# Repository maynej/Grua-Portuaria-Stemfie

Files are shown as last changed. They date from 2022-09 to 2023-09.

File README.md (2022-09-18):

# Grua-Portuaria-Stemfie

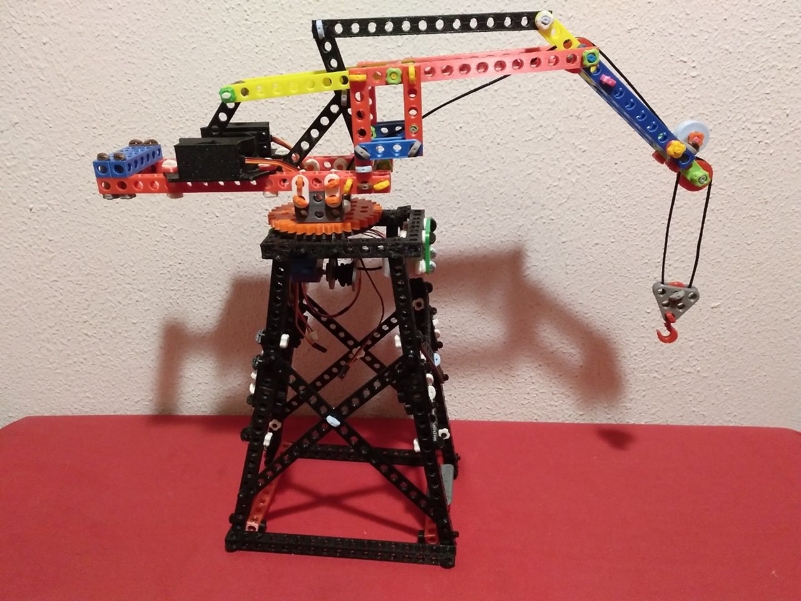
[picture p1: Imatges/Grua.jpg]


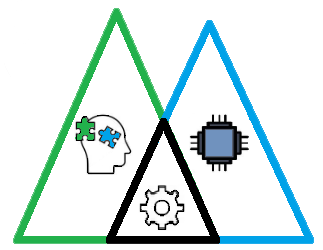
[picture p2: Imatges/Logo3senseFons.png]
Realitzada per [Jordi Mayné](https://github.com/maynej) des de Mechatronic Study 

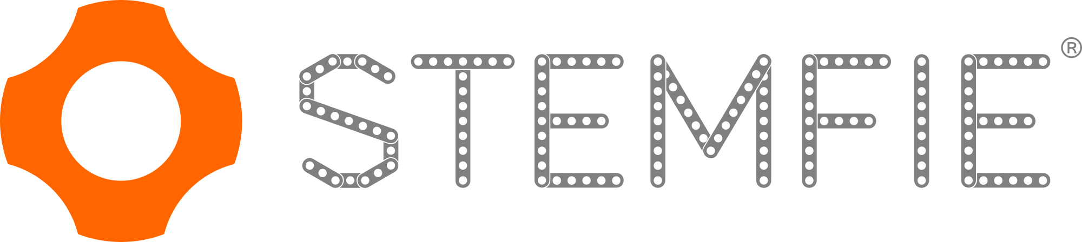
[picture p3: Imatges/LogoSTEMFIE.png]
STEMFIE es un projecte de construcció lliure, que s'imprimeix en 3D (http://stemfie.org) 

Electronics Stemfie es una llibreria STL de suports per tarjes de control, sensors i actuadors amb compatibilitat Stemfie.

[Electronics Suports amb compatibilitat Stemfie](https://github.com/maynej/Electronics-Stemfie), pretén facilitar l'automatització de les construccions amb targes Arduino, Microbit, ESP32 Steamakers... 

La documentació està disponible també en castellà i anglés [en PDF](https://github.com/maynej/Grua-Portuaria-Stemfie/tree/main/DOC)

# Torre base

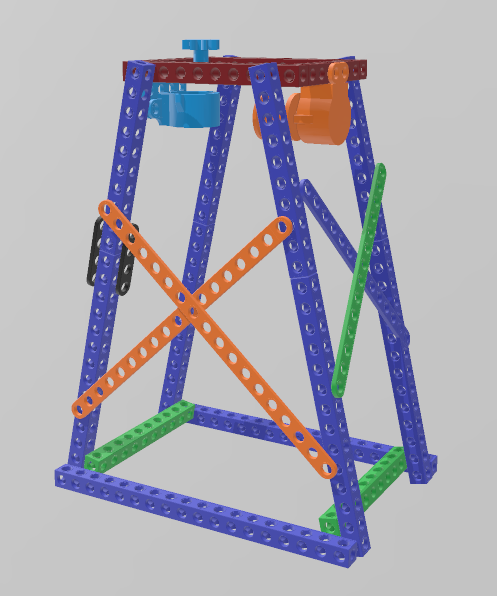
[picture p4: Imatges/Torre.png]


STL per imprimir la Torre Base [aquí](https://github.com/maynej/Grua-Portuaria-Stemfie/tree/main/STL/Base)

# Plataforma giratòria

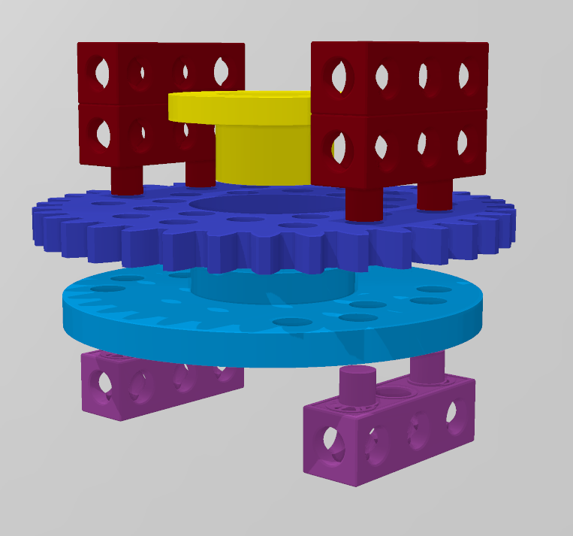
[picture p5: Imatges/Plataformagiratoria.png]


STL per imprimir la Plataforma Giratòria [aquí](https://github.com/maynej/Grua-Portuaria-Stemfie/tree/main/STL/PlataformaGiratoria)

# Ploma

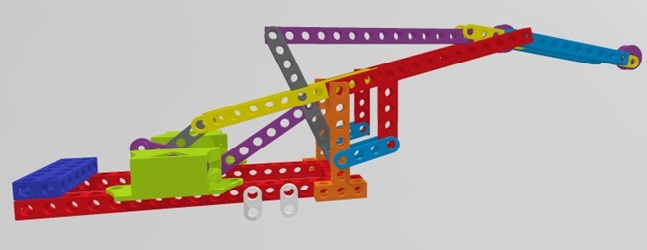
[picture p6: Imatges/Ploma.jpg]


STL per imprimir la Ploma articulada [aquí](https://github.com/maynej/Grua-Portuaria-Stemfie/tree/main/STL/Ploma)

# Ganxo

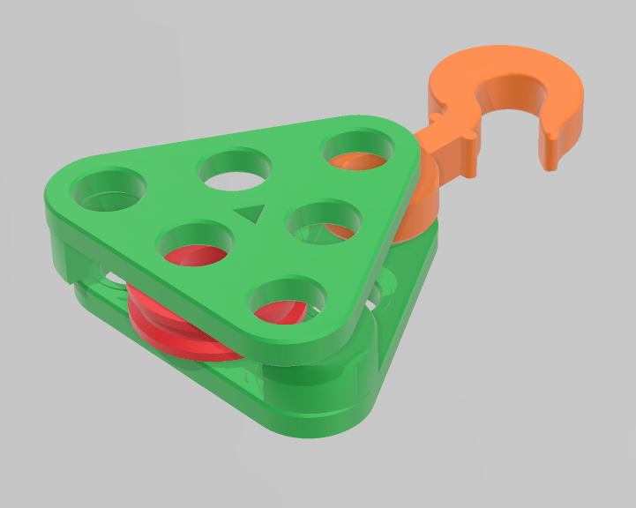
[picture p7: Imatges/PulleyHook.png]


STL per imprimir el Ganxo [aquí](https://github.com/maynej/Grua-Portuaria-Stemfie/tree/main/STL/Ganxo)

## Mesurador Stemfie 

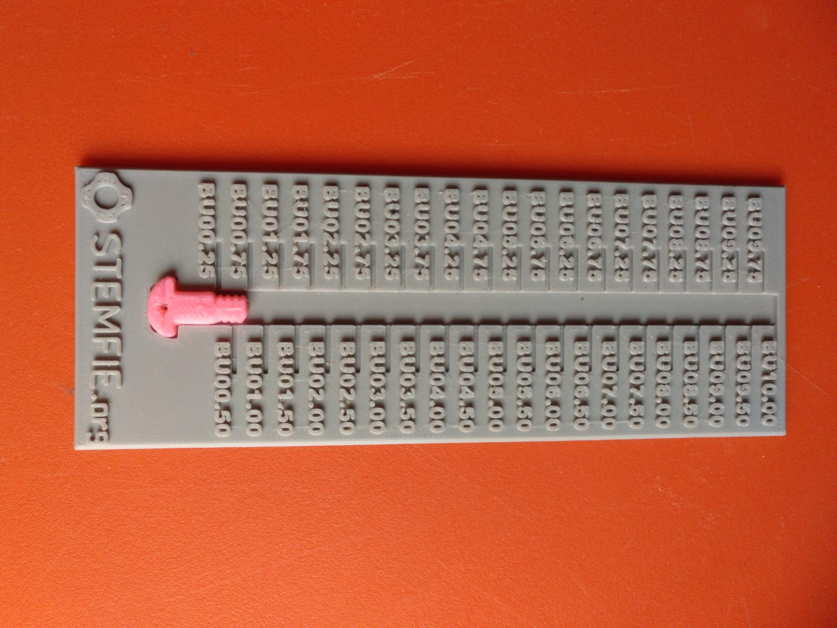
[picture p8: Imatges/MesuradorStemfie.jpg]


Descripció    | Opcional     | Arxiu         
------------- | ------------ | ----- 
Mesurador Cargols | 1  | [Mesurador](STL/MesuraStemfie2.stl)

## Llicència

Creative Commons Attribution-NoComercial-ShareAlike 4.0 International (CC BY-NC-SA 4.0)

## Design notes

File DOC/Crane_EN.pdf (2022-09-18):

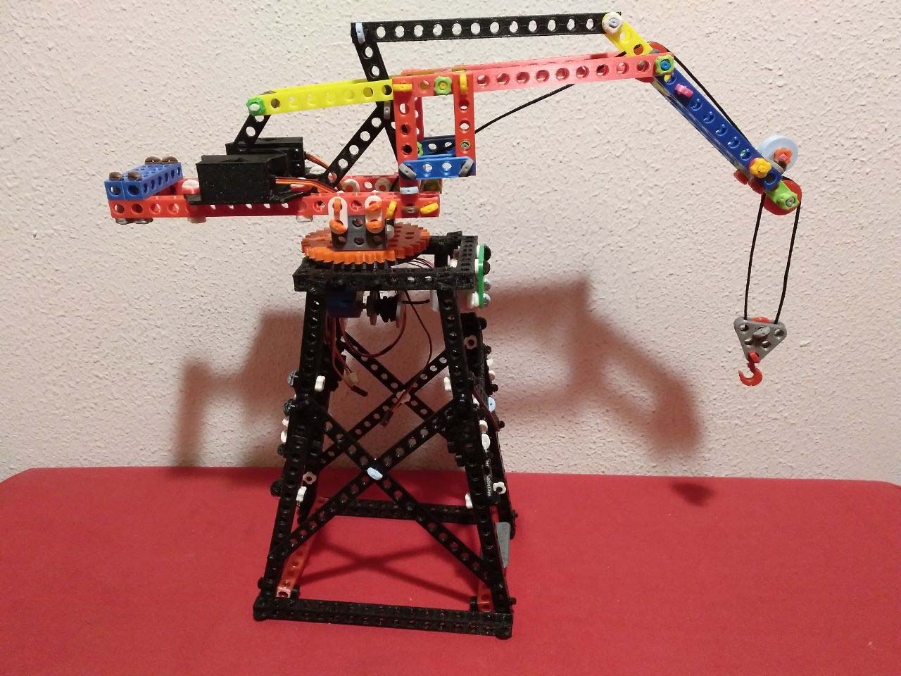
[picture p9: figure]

PORT CRANE – 2022 | 1 | JORDI MAYNE

## Port crane

This harbor crane is a reproduction with Stemfie parts(www.stemfie.org). It allows to be a tool for assembly skills and programming the control, the structure is formed by a tower base, the articulated boom and counterweight.

The screws are pieces that are not currently used in commercial toys, the pieces are joined based on easy assemblies, but the people lose the opportunity to gain hand skill and dexterity to place the screws and turn the nuts.

The control is composed by two power servomotors for to move the articulated boom, a stepper motor for the 360 degree rotation and another for the rope for rope winding drum.

These motors are controlled by an Arduino Uno or ESP32 Steamakers board and two joysticks, LED light to indicate movements and a buzzer.

Alternatively, it can be controlled via a Bluetooth mobile phone app.

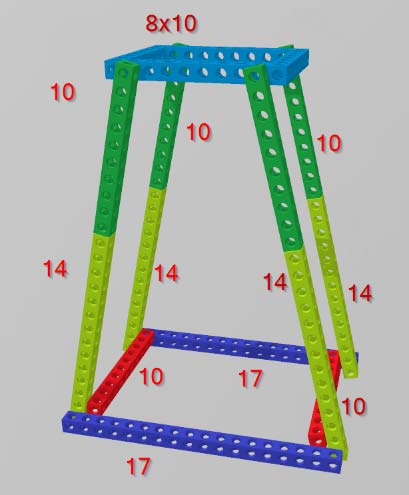
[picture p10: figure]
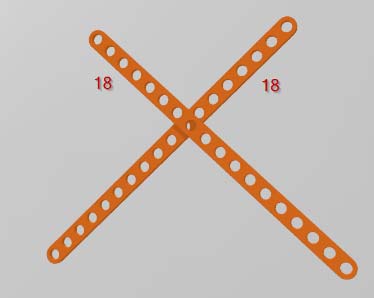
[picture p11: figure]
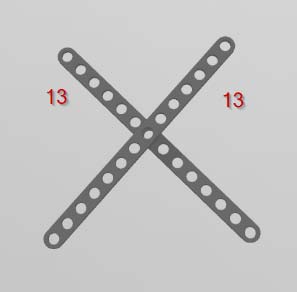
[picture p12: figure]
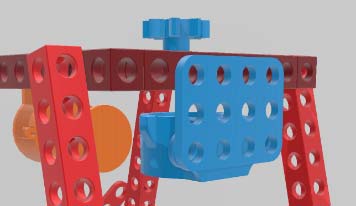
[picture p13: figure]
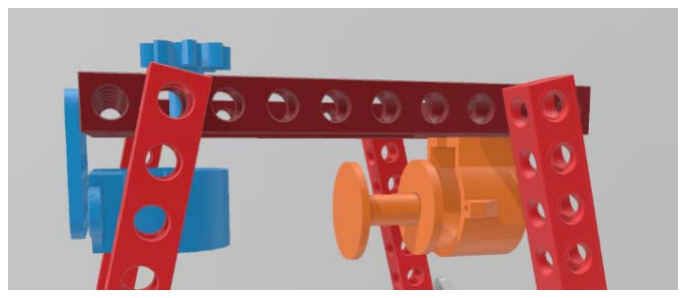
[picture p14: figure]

PORT CRANE – 2022 | 2 | JORDI MAYNE

### Mounting

Tower

The structure will also contain the power supply, the control unit and the stepper motors. In the upper part of this structure, the rotating platform will be housed, which allows turn 360‐degree and supports the articulated boom.

2 Beam17 | 4 ScrewBU02.00 | 4 Nuts
4 Beam14 | 4 ScrewBU02.00 | 4 Nuts
6 Beam10 | 4 ScrewBU02.00 | 4 Nuts

1 Base8x10

16 Brace4 | 16 ScrewBU01.50 | 16 Nuts
4 Brace18 | 2 ScrewBU00.50 | 8 ScrewBU01.25 | 10 Nuts
4 Brace13 | 2 ScrewBU00.50 | 8 ScrewBU01.25 | 10 Nuts
4 ScrewBU02.00 | 4 Nuts

Stepper Motors

Platform Motor

1 28BYJ‐48_2H_Stemfie | Gear28BYJ‐48_130mm
1 STR_STD_BRM‐4x3 | 2 ScrewBU01.50 | 2 Nuts 2 Washer2.5mm

Pulley Hook Motor

28BYJ‐48_4H_Stemfie | 1 Spool28BYJ‐48 | 2 ScrewBU01.25 2 Nuts

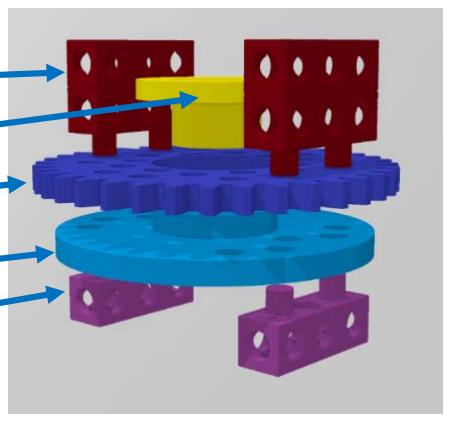
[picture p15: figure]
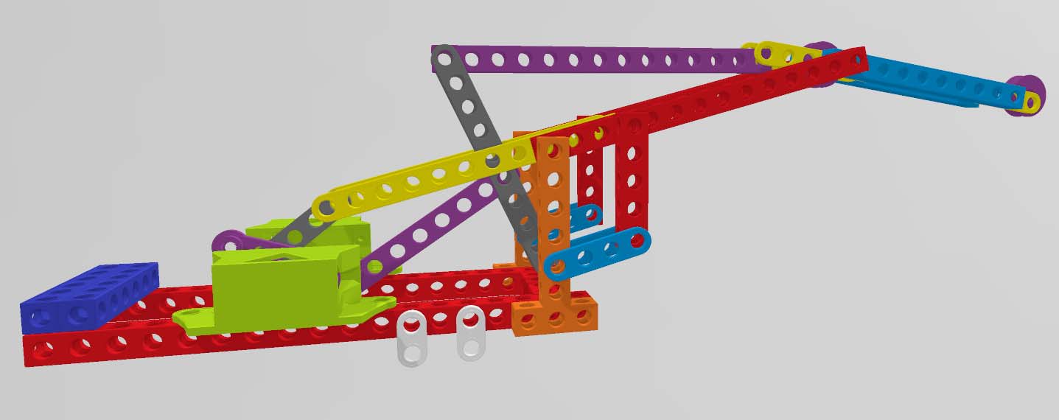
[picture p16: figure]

PORT CRANE – 2022 | 3 | JORDI MAYNE

Rotating Platform

This platform allows to rotate 360 degrees the articulated boom, it is fixed to the structure base. The yellow part should be glued to the light blue disc to ensure that the dark blue gear can rotate freely and will not come apart. The blocks are inserted in the disc and in the gear, they will serve to seat the base8x10 and the articulated boom.

2 BlocGrua3x2

1 TapEngranatgeGrua

1 EngranatgeGrua

1 DiscEngranatge

2 BlocGrua3x1

These parts have been specially designed for this mount, but comply with Stemfie compliances.

Articulating boom and counterweight

The crane boom is an articulated boom type and the counterweight area contains two servomotors for the movements of articulated boom.

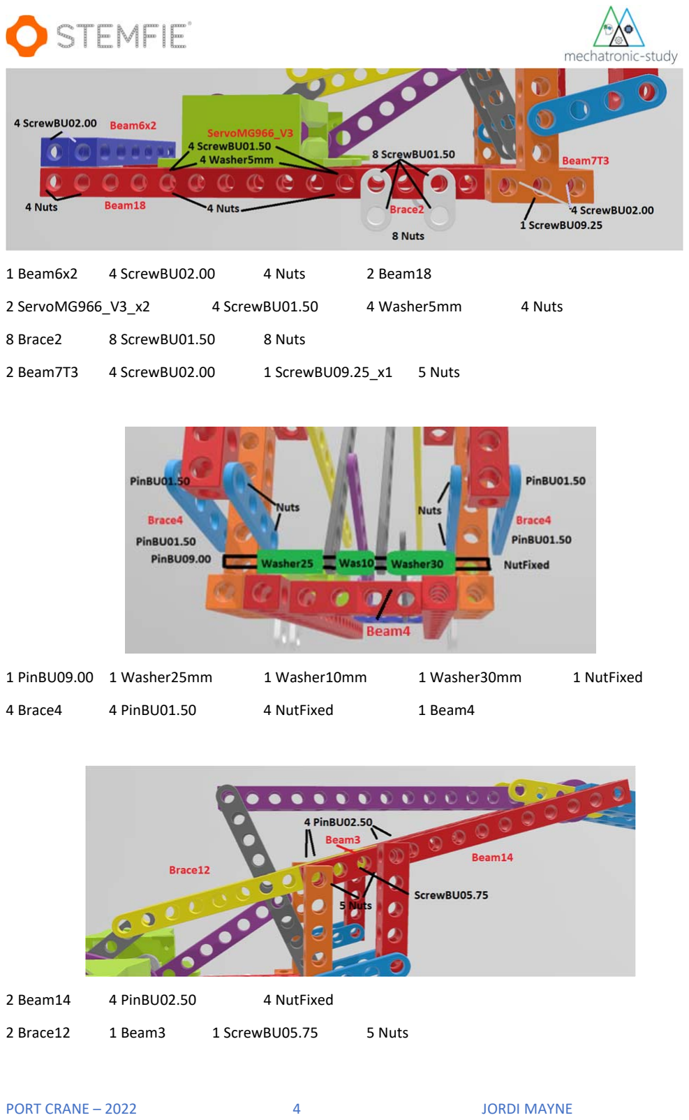
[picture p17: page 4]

PORT CRANE – 2022 | 4 | JORDI MAYNE
1 Beam6x2 | 4 ScrewBU02.00 | 4 Nuts | 2 Beam18
2 ServoMG966_V3_x2 | 4 ScrewBU01.50 | 4 Washer5mm | 4 Nuts
8 Brace2 | 8 ScrewBU01.50 | 8 Nuts
2 Beam7T3 | 4 ScrewBU02.00 | 1 ScrewBU09.25_x1 | 5 Nuts
1 PinBU09.00 1 Washer25mm | 1 Washer10mm | 1 Washer30mm | 1 NutFixed
4 Brace4 | 4 PinBU01.50 | 4 NutFixed | 1 Beam4
2 Beam14 | 4 PinBU02.50 | 4 NutFixed
2 Brace12 | 1 Beam3 | 1 ScrewBU05.75 | 5 Nuts

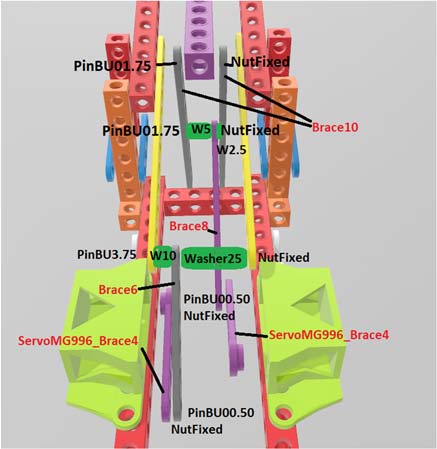
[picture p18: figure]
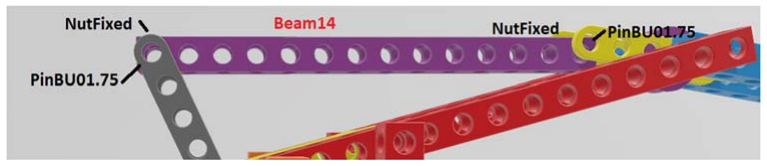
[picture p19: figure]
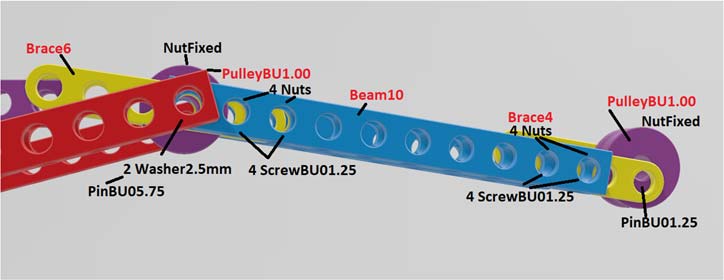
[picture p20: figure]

PORT CRANE – 2022 | 5 | JORDI MAYNE
1 PinBU01.75 | 1 NutFixed | 2 Brace10
1 PinBU01.75 | 1 Washer5mm | 1 Brace8 | 1Washer2.5mm | 1 NutFixed
1 PinBU03.75 | 1 Washer10mm | 1 Brace6 | 1 Washer25mm | 1 NutFixed
2 ServoMG996_Brace4 | 2 PinBU00.50 2 NutFixed
1 Beam14 | 2 PinBU01.75 | 2 NutFixed
2 Beam10 | 1 PinBU05.75 1 Washer2.5mm 1 PulleyBU1.00 1 Washer2.5mm 1 NutFixed
2 Brace6 | 4 ScrewBU01.25 | 4 Nuts
2 Brace4 | 4 ScrewBU01.25 | 4 Nuts | 1 PulleyBU1.00 | PinBU01.25 | 1 NutFixed

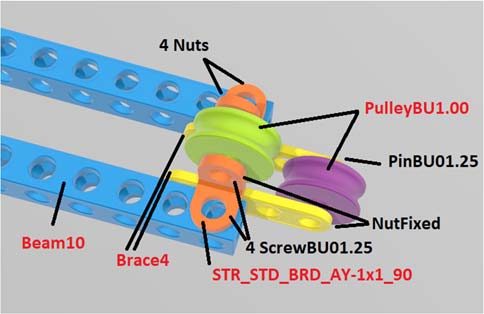
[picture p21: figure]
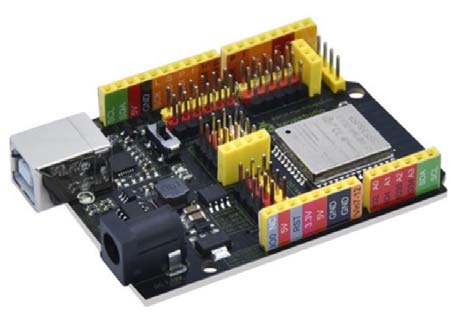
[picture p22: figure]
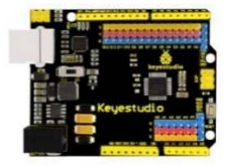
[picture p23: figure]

PORT CRANE – 2022 | 6 | JORDI MAYNE

Improvement of hook rope

2 STR_STD_BRD_AY‐1x1_90 4 ScrewBU01.25 4 Nuts | 1 PulleyBU1.00 | 1 PinBU01.25 1 NutFixed

### Unit Control

Arduino UNO | ESP32 Steamakers

### Software used

http://www.arduinoblocks.com/

PORT CRANE – 2022 | 7 | JORDI MAYNE

https://www.bigrentz.com/blog/what‐is‐a‐crane‐boom

https://www.bigrentz.com/blog/types‐of‐cranes

https://www.curioushistory.com/history‐of‐the‐crane‐from‐inventions‐to‐improvements/

PORT CRANE – 2022 | 8 | JORDI MAYNE

Port cranes play a vital role in day‐to‐day port operations.

# Port Cranes: Everything You Need to Know

## Port cranes play a vital role in day-to-day port operations. Without the help of these cranes, containers can’t be stacked in the yard or loaded on the vessel. There are two types of port cranes: quay cranes and yard

cranes.

## - Quay Cranes: These types of cranes are used to work on containers from ship to shore and shore to ship and are therefore also known as ship-to-shore cranes (STS). Quay cranes are located

along the quayside where container ships are easily accessible.

## - Yard Cranes: These types of cranes are primarily located in the port’s container yard, and move laden containers from the yard to trailers. While there are several types of yard cranes, the most common ones are Rail-Mounted Gantry Cranes (RMG) and

Rubber-Tired Gantry Cranes (RTG).

## When it comes to ship-to-shore port cranes, there are two types: the high profile (with an A-frame) and the low profile. Though they function the same way, it is during the container port design process where the crane

type is decided, based on suitability.

## The low profile crane features a fixed boom to load containers off and onto the vessel. It’s designed and used for scenarios where the seaport is near an airport so that aircrafts are not distracted or blocked by the

cranes.

## On the other hand, high profile port cranes have a hinged boom that

allows for easier ship navigation when berthing or leaving the dock.

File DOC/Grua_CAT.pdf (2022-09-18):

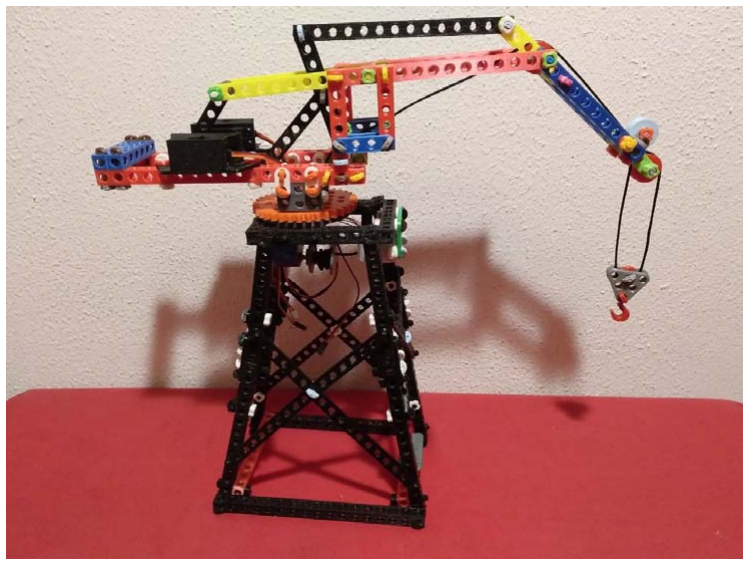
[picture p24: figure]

GRUA PORTUARIA – 2022 | 1 | JORDI MAYNE

## Grua portuària

Aquesta grua portuària es una reproducció amb peces Stemfie (www.stemfie.org). Permet ser una eina d’habilitat de muntatge i programació de control, l’estructura està formada per una torre que dona altura, la ploma articulada i contrapès.

Els cargols son peces que actualment no es van fer servir en els muntatges comercials, s’uneixen les peces a base d’assemblatges fàcils, però, a la vegada perden l’oportunitat d’agafar una habilitat manual i destresa per col∙locar‐los i girar les femelles.

El control està format per dos servomotors de potencia per el moviment de la ploma articulada, un motor pas a pas per el gir de la ploma 360 graus i l’altre per el tambor de recollida de corda.

Aquests motors estan controlats per una placa Arduino UNO o Steamakers ESP32 i manipulats mitjançant dos joysticks, una llum de color a LED per indicar moviment de la mateixa i un brunzidor per donar una senyal acústica.

Alternativament podrà controlar‐se mitjançant una aplicació de telèfon mòbil i Bluetooth.

Comentado [J1]:

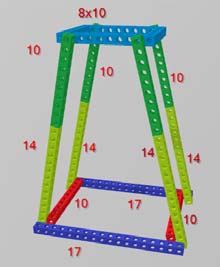
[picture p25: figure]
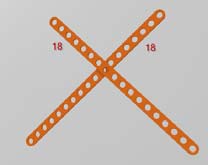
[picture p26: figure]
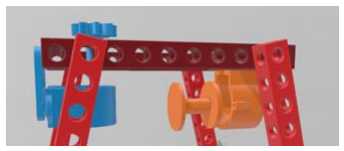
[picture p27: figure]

GRUA PORTUARIA – 2022 | 2 | JORDI MAYNE

### Muntatge

Estructura de la torre

L’estructura de la torre tindrà a més de l’alimentació, la unitat de control i els motors pas a pas. En la part superior d’aquesta estructura s’allotjarà la plataforma giratòria que permet un gir de 360 graus i sustentar la ploma articulada.

2 Beam17 | 4 ScrewBU02.00 | 4 Nuts
4 Beam14 | 4 ScrewBU02.00 | 4 Nuts
6 Beam10 | 4 ScrewBU02.00 | 4 Nuts

1 Base8x10

16 Brace4 | 16 ScrewBU01.50 | 16 Nuts
4 Brace18 | 2 ScrewBU00.50 | 8 ScrewBU01.25 | 10 Nuts
4 Brace13 | 2 ScrewBU00.50 | 8 ScrewBU01.25 | 10 Nuts
4 ScrewBU02.00 | 4 Nuts

Motors pas a pas

Motor Plataforma

1 28BYJ‐48_2H_Stemfie | Gear28BYJ‐48_130mm
1 STR_STD_BRM‐4x3 | 2 ScrewBU01.50 | 2 Nuts 2 Washer2.5mm

Motor politja

28BYJ‐48_4H_Stemfie | 1 Spool28BYJ‐48 | 2 ScrewBU01.25 2 Nuts

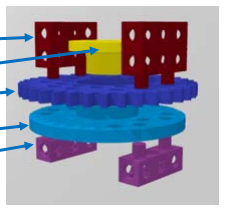
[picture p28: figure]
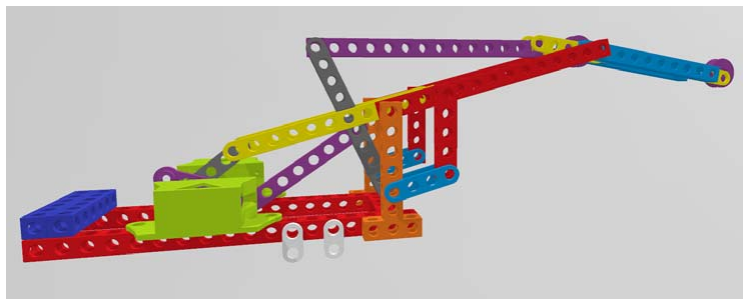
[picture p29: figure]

GRUA PORTUARIA – 2022 | 3 | JORDI MAYNE

Plataforma giratòria

Aquesta plataforma permet girar la ploma articulada de 360 graus, es fixe a l’estructura base i es pot desmuntar en bloc fàcilment junt amb la ploma articulada per el seu transport. La peça groga cal enganxar‐la al disc blau clar pera assegurar que pugui girar l’engranatge blau fosc amb tota llibertat i no es desmunti. Els blocs s’insereixen en el disc i en l’engranatge, serviran per assentar‐se a la base8x10 i la ploma articulada.

2 BlocGrua3x2

1 TapEngranatgeGrua

1 EngranatgeGrua

1 DiscEngranatge

2 BlocGrua3x1

Son peces dissenyades especialment per aquest muntatge, però, compleixen amb les distancies Stemfie.

Ploma articulada i contrapès

La ploma de la grua es del tipus articulada i la zona de contrapès te els dos servomotors per els moviments de la ploma.

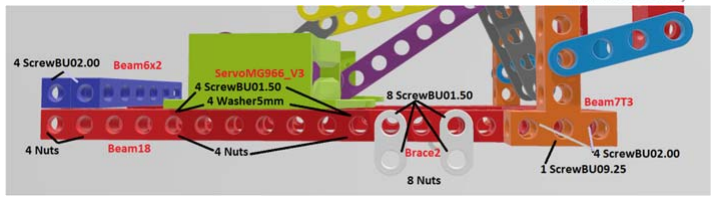
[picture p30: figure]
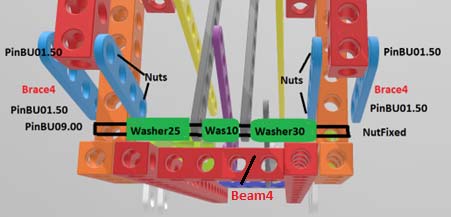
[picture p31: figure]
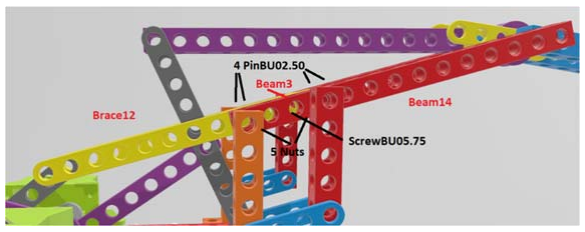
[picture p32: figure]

GRUA PORTUARIA – 2022 | 4 | JORDI MAYNE
1 Beam6x2 | 4 ScrewBU02.00 | 4 Nuts | 2 Beam18
2 ServoMG966_V3_x2 | 4 ScrewBU01.50 | 4 Washer5mm | 4 Nuts
8 Brace2 | 8 ScrewBU01.50 | 8 Nuts
2 Beam7T3 | 4 ScrewBU02.00 | 1 ScrewBU09.25_x1 | 5 Nuts
1 PinBU09.00 1 Washer25mm | 1 Washer10mm | 1 Washer30mm | 1 NutFixed
4 Brace4 | 4 PinBU01.50 | 4 NutFixed | 1 Beam4
2 Beam14 | 4 PinBU02.50 | 4 NutFixed
2 Brace12 | 1 Beam3 | 1 ScrewBU05.75 | 5 Nuts


GRUA PORTUARIA – 2022 | 5 | JORDI MAYNE
1 PinBU01.75 | 1 NutFixed | 2 Brace10
1 PinBU01.75 | 1 Washer5mm | 1 Brace8 | 1Washer2.5mm | 1 NutFixed
1 PinBU03.75 | 1 Washer10mm | 1 Brace6 | 1 Washer25mm | 1 NutFixed
2 ServoMG996_Brace4 | 2 PinBU00.50 2 NutFixed
1 Beam14 | 2 PinBU01.75 | 2 NutFixed
2 Beam10 | 1 PinBU05.75 1 Washer2.5mm 1 PulleyBU1.00 1 Washer2.5mm 1 NutFixed
2 Brace6 | 4 ScrewBU01.25 | 4 Nuts
2 Brace4 | 4 ScrewBU01.25 | 4 Nuts | 1 PulleyBU1.00 | PinBU01.25 | 1 NutFixed


GRUA PORTUARIA – 2022 | 6 | JORDI MAYNE

Millora per la corda ganxo

2 STR_STD_BRD_AY‐1x1_90 4 ScrewBU01.25 4 Nuts | 1 PulleyBU1.00 | 1 PinBU01.25 1 NutFixed

https://www.youtube.com/watch?v=ROM8IcVBme4&ab_channel=TecnoCesto

SERVO + Joystick


GRUA PORTUARIA – 2022 | 7 | JORDI MAYNE

TEST MOTOR PASO A PASO 28BYJ-48


GRUA PORTUARIA – 2022 | 8 | JORDI MAYNE

https://www.bigrentz.com/blog/what‐is‐a‐crane‐boom

https://www.bigrentz.com/blog/types‐of‐cranes

https://www.curioushistory.com/history‐of‐the‐crane‐from‐inventions‐to‐improvements/

Port crane

GRUA PORTUARIA – 2022 | 9 | JORDI MAYNE

### Parts d’una grua

Seguidament es detallen les diferents parts d’una grua torre.

La ploma
Està conformada per estructures metàl∙liques triangulades. Gràcies als seus carrils, la grua te la capacitat per girar i desplaçar‐se.

Els contrapesos
Son blocs de formigó que es col∙loquen en la contra ploma per disminuir la carrega o l’esforç generat per la ploma.

La contra ploma
Es on es col∙loquen els contrapesos per contrarestar la carrega. Al igual que la ploma, la contra ploma es troba també unida a la torre, però, en aquest cas, mitjançant una gelosia.

Els tirants
Aguanten tant la contra‐ploma como la ploma, i poden ser de cable o d’acer.

El porta ploma
També conegut amb “castillete”, realitza funcions d’ancoratge. A més de fixar els tensors, inclou escales i baranes per permetre el pas dels operaris.

La plataforma giratòria
Està situada en la part alta de la torre, i alberga tant la ploma com la contra‐ploma. Gràcies a l’unió de tots aquests elements, la grua pot girar fins a 360º. En ocasions, la cabina de control pot estar ubicada en aquesta plataforma.

La torre
Sota la plataforma giratòria i tots els seus accessoris es troba la torre, formada por mòduls. Aquest fet fa possible ajustar l’altura de la grua en funció de las necessitats.

El llast
Gràcies al llast la grua es manté en peu, a pesar del seu propi pes, del de la carrega i de la intensitat del vent mentre es realitzen els treballs. Acostuma a estar format per blocs de formigó situats a la base de la grua.

El carro de ploma
Aquest element es mou al llarg de la ploma per mitjà d'un sistema de rails, i la seva altura s'ajusta gràcies a les politges.

Las politges
Sense elles no seria possible fer els moviments d'elevació ni de translació. Hi ha bàsicament quatre tipus de politges: laminades, d'acer soldat, d'acer emmotllat i de fosa nodular.

El tambor
Al tambor es recullen els cables per desplaçar les càrregues i el carro. Els més usats són els tambors d'una capa, encara que també hi ha models de diverses.

El ganxo
És un element clau, ja que serveix per subjectar la càrrega. El seu disseny escrupolós i segur serà clau per evitar que es produeixin xocs que puguin derivar en accidents.

GRUA PORTUARIA – 2022 | 10 | JORDI MAYNE

Els motors
Segons quins siguin els moviments que pugui executar la grua, aquesta disposarà de més o menys motors. Normalment, els que es fan servir són motors elèctrics trifàsics.

Els frens
Són imprescindibles per limitar el moviment, sigui del tipus que sigui. Hi ha diferents classes de frens: cònics, de mordasses i de cinta.

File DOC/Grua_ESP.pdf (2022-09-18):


GRUA PORTUARIA – 2022 | 1 | JORDI MAYNE

## Grúa portuaria

Esta grúa portuaria es una reproducción con piezas Stemfie (www.stemfie.org) . Permite ser una herramienta de habilidad de montaje y programación de control, la estructura está formada por una torre base que da altura, la pluma articulada y contrapeso.

Los tornillos son piezas que actualmente no se usan en los montajes comerciales, se unen las piezas a base de ensamblajes fáciles, pero a la vez pierden la oportunidad de coger una habilidad manual y destreza para colocar los mismos y girar las tuercas.

El control está formado por dos servomotores de potencia para el movimiento de la pluma articulada, un motor paso a paso para el giro de la pluma 360 grados y otro para el tambor de recogida de cuerda.

Estos motores están controlados por una placa Arduino Uno o Steamakers ESP32 y manipulados mediante dos joysticks, una luz de color para indicar movimiento de la misma y otro acústico.

Alternativamente podrá controlarse mediante una aplicación de teléfono móvil por Bluetooth.


GRUA PORTUARIA – 2022 | 2 | JORDI MAYNE

### Montaje

Estructura Base

La estructura contendrá además la alimentación, la unidad de control y los motores paso a paso. En la parte superior de esta estructura se alojará la plataforma giratoria que permite un giro de 360 grados y sustentar la pluma articulada.

2 Beam17 | 4 ScrewBU02.00 | 4 Nuts
4 Beam14 | 4 ScrewBU02.00 | 4 Nuts
6 Beam10 | 4 ScrewBU02.00 | 4 Nuts

1 Base8x10

16 Brace4 | 16 ScrewBU01.50 | 16 Nuts
4 Brace18 | 2 ScrewBU00.50 | 8 ScrewBU01.25 | 10 Nuts
4 Brace13 | 2 ScrewBU00.50 | 8 ScrewBU01.25 | 10 Nuts
4 ScrewBU02.00 | 4 Nuts

Motores paso a paso

Motor Plataforma

1 28BYJ‐48_2H_Stemfie | Gear28BYJ‐48_130mm
1 STR_STD_BRM‐4x3 | 2 ScrewBU01.50 | 2 Nuts 2 Washer2.5mm

Motor polea

28BYJ‐48_4H_Stemfie | 1 Spool28BYJ‐48 | 2 ScrewBU01.25 2 Nuts


GRUA PORTUARIA – 2022 | 3 | JORDI MAYNE

Plataforma giratoria

Esta plataforma permite girar la pluma articulada de 360 grados, se fija en la estructura base y permite ser desmontada en bloque fácilmente junto con la pluma articulada para su transporte. La pieza amarilla se debe pegar al disco azul claro para asegurar que pueda girar el engranaje azul oscuro con toda libertad y no se desmonte. Los bloques se insertan en el disco y en el engranaje, servirán para asentarse a la base8x10 y la pluma articulada.

2 BlocGrua3x2

1 TapEngranatgeGrua

1 EngranatgeGrua

1 DiscEngranatge

2 BlocGrua3x1

Son piezas diseñadas especialmente para este montaje, pero cumplen con las distancias Stemfie.

Pluma articulada y contrapeso

La pluma de la grúa es del tipo articulada y la zona de contrapeso contiene los dos servomotores para los movimientos de la pluma.


GRUA PORTUARIA – 2022 | 4 | JORDI MAYNE
1 Beam6x2 | 4 ScrewBU02.00 | 4 Nuts | 2 Beam18
2 ServoMG966_V3_x2 | 4 ScrewBU01.50 | 4 Washer5mm | 4 Nuts
8 Brace2 | 8 ScrewBU01.50 | 8 Nuts
2 Beam7T3 | 4 ScrewBU02.00 | 1 ScrewBU09.25_x1 | 5 Nuts
1 PinBU09.00 1 Washer25mm | 1 Washer10mm | 1 Washer30mm | 1 NutFixed
4 Brace4 | 4 PinBU01.50 | 4 NutFixed | 1 Beam4
2 Beam14 | 4 PinBU02.50 | 4 NutFixed
2 Brace12 | 1 Beam3 | 1 ScrewBU05.75 | 5 Nuts


GRUA PORTUARIA – 2022 | 5 | JORDI MAYNE
1 PinBU01.75 | 1 NutFixed | 2 Brace10
1 PinBU01.75 | 1 Washer5mm | 1 Brace8 | 1Washer2.5mm | 1 NutFixed
1 PinBU03.75 | 1 Washer10mm | 1 Brace6 | 1 Washer25mm | 1 NutFixed
2 ServoMG996_Brace4 | 2 PinBU00.50 2 NutFixed
1 Beam14 | 2 PinBU01.75 | 2 NutFixed
2 Beam10 | 1 PinBU05.75 1 Washer2.5mm 1 PulleyBU1.00 1 Washer2.5mm 1 NutFixed
2 Brace6 | 2 ScrewBU01.25 | 2 Nuts
2 Brace4 | 4 ScrewBU01.25 | 4 Nuts | 1 PulleyBU1.00 | PinBU01.25 | 1 NutFixed


GRUA PORTUARIA – 2022 | 6 | JORDI MAYNE

Mejora para la cuerda del gancho

2 STR_STD_BRD_AY‐1x1_90 4 ScrewBU01.25 4 Nuts | 1 PulleyBU1.00 | 1 PinBU01.25 1 NutFixed

### Unidad de Control

Arduino UNO | ESP32 Steamakers

### Software utilizado

http://www.arduinoblocks.com/

GRUA PORTUARIA – 2022 | 7 | JORDI MAYNE

### Partes de una grúa

Seguidamente se detallan las diferentes partes de una grúa torre.

La pluma
Está conformada por estructuras metálicas trianguladas. Gracias a sus carriles, la grúa tiene capacidad para girar y desplazarse.

Los contrapesos
Son bloques de hormigón que se colocan en la contrapluma para disminuir la carga o el esfuerzo generado por la pluma.

La contrapluma
Donde se colocan los contrapesos para contrarrestar la carga. Al igual que la pluma, la contrapluma se encuentra también unida a la torre, pero, en este caso, mediante una celosía.

Los tirantes
Aguantan tanto la contrapluma como la pluma, y pueden ser de cable o de acero.

El portapluma
También conocido como castillete, realiza funciones de anclaje. Además de fijar los tensores, incluye escaleras y barandillas para permitir el paso de los operarios.

La plataforma giratoria
Está situada en la parte alta de la torre, y alberga tanto la pluma como la contrapluma. Gracias a la unión de todos estos elementos, la grúa puede girar hasta 360º. En ocasiones, la cabina de control puede estar ubicada en esta plataforma.

La torre
Bajo la plataforma giratoria y todos sus accesorios se encuentra la torre, formada por módulos. Este hecho hace posible ajustar la altura de la grúa en función de las necesidades.

El lastre
Gracias al lastre la grúa se mantiene en pie, a pesar de su propio peso, del de la carga y de la intensidad del viento mientras se realicen los trabajos. Suele estar formado por una zapata o por bloques de hormigón situados en la base de la grúa.

El carro de pluma
Este elemento se mueve a lo largo de la pluma por medio de un sistema de raíles, y su altura se ajusta gracias a las poleas.

Las poleas
Sin ellas no sería posible realizar los movimientos de elevación ni de traslación. Existen básicamente cuatro tipos de poleas: laminadas, de acero soldado, de acero moldeado y de fundición nodular.

El tambor
En el tambor se recogen los cables para desplazar las cargas y el carro. Los más usados son los tambores de una capa, aunque también existen modelos de varias.

El gancho
Es un elemento clave, pues sirve para sujetar la carga. Su escrupuloso y seguro diseño será clave para evitar que se produzcan choques que puedan derivar en accidentes.

GRUA PORTUARIA – 2022 | 8 | JORDI MAYNE

Los motores
Según cuáles sean los movimientos que pueda ejecutar la grúa, esta dispondrá de más o menos motores. Normalmente, los que se utilizan son motores eléctricos trifásicos.

Los frenos
Son imprescindibles para limitar el movimiento, sea del tipo que sea. Existen diferentes clases de frenos: cónicos, de mordazas y de cinta.

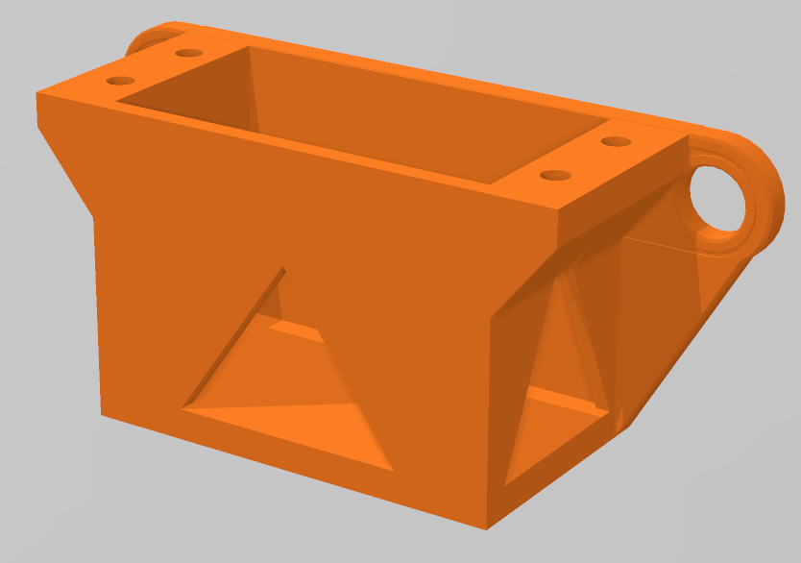
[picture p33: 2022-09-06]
Imatges/-ServoMG966_V3.png

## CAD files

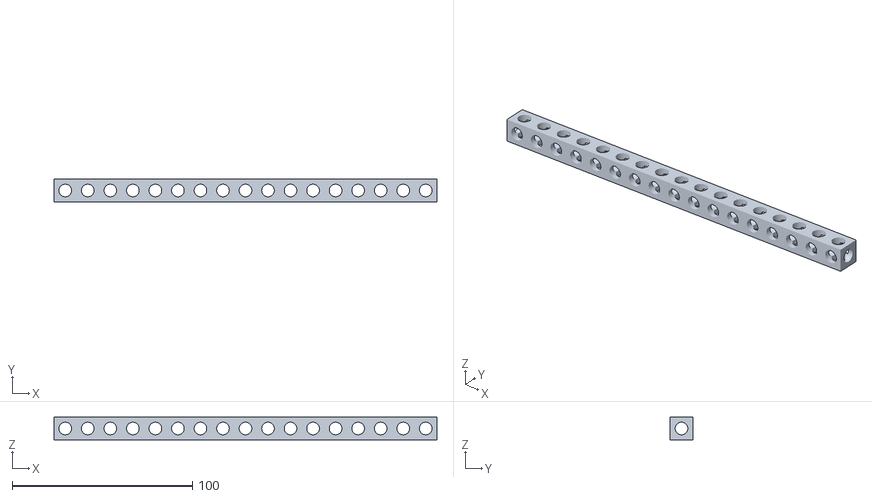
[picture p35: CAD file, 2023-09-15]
STL/Base/Beam17_x2.stl
212.5 x 12.5 x 12.5

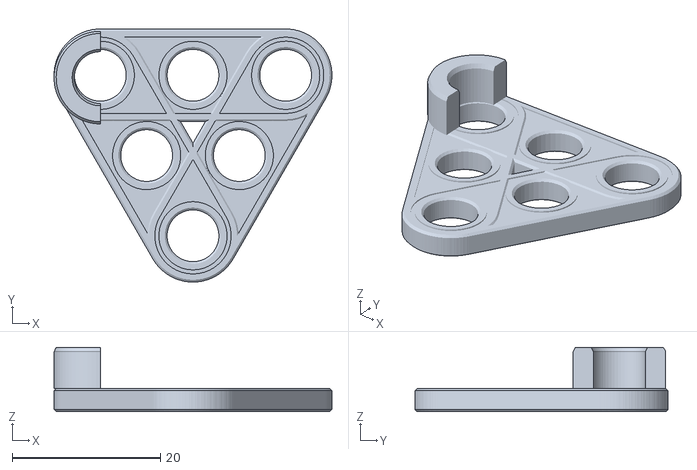
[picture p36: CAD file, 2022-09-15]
STL/Ganxo/PulleyHolder_x2.stl
37.5 x 34.1 x 8.68

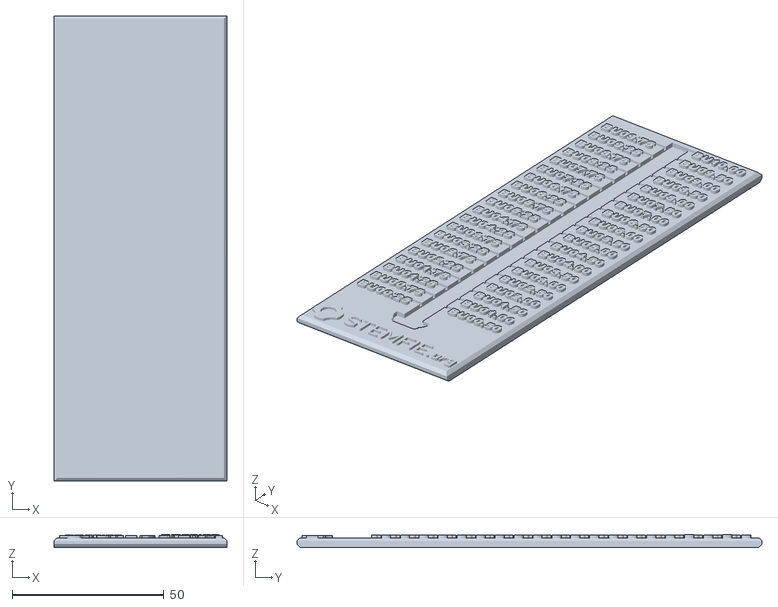
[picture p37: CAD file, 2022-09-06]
STL/MesuraStemfie2.stl
57.0 x 153.4 x 4.13

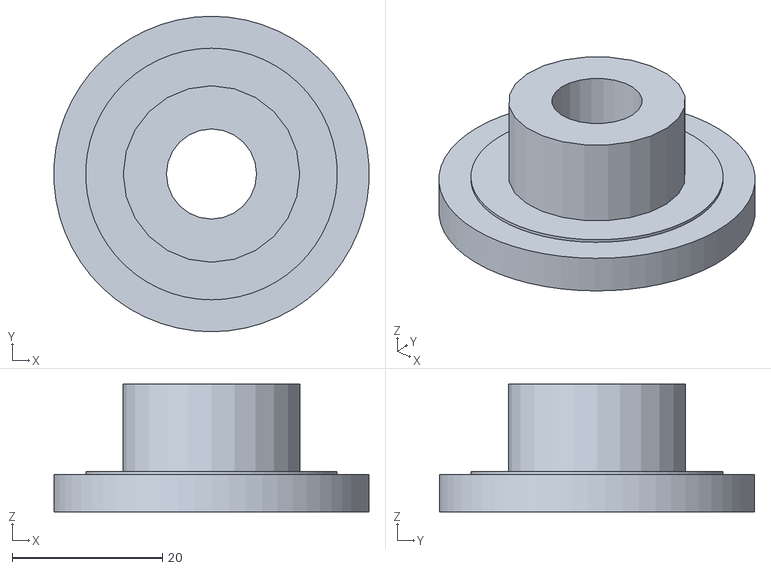
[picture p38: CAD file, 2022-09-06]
STL/PlataformaGiratoria/TapEngranatgeGrua_x1.stl
41.9 x 42.0 x 17.0

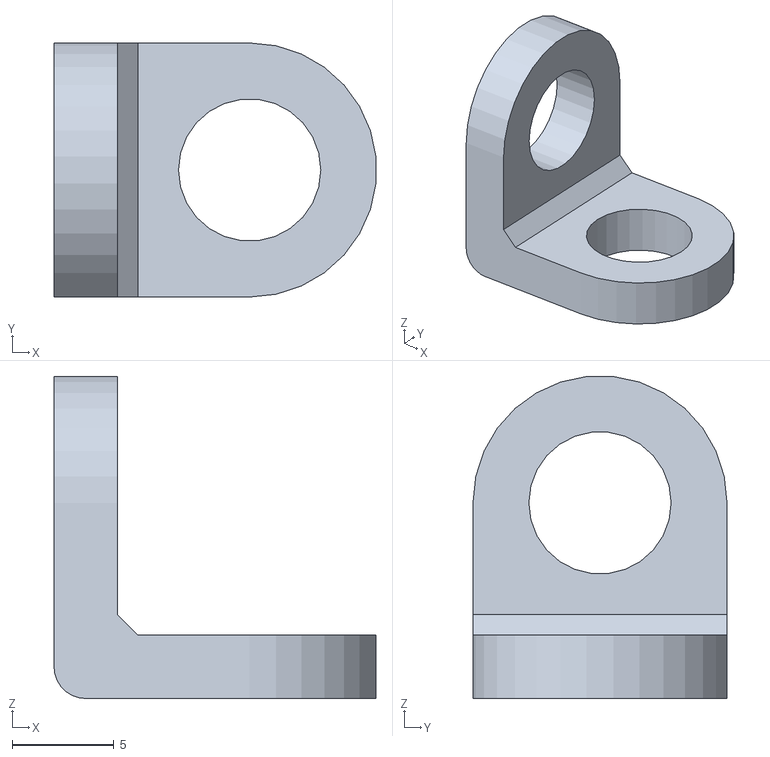
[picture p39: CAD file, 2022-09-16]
STL/Ploma/STR_STD_BRD_AY-1x1_90_x2.stl
15.8 x 12.5 x 15.8

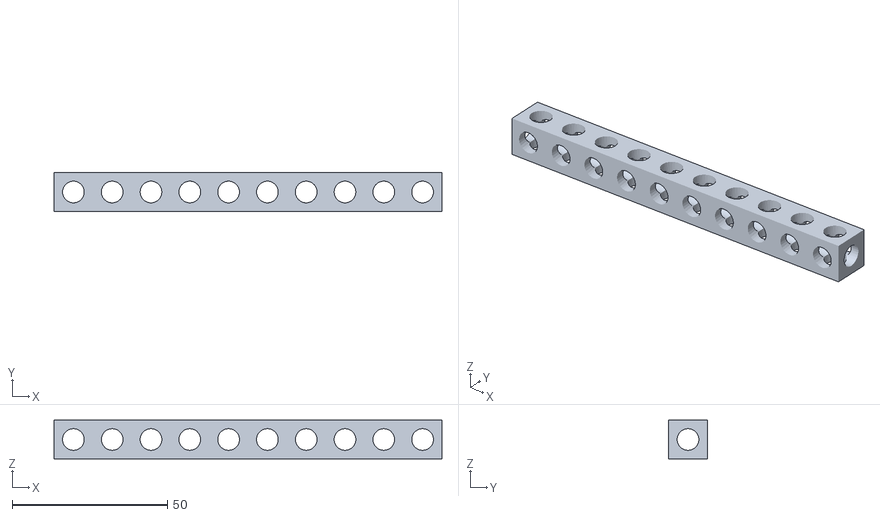
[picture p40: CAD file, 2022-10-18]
STL/Base/Beam10_x2.stl
125.0 x 12.5 x 12.5

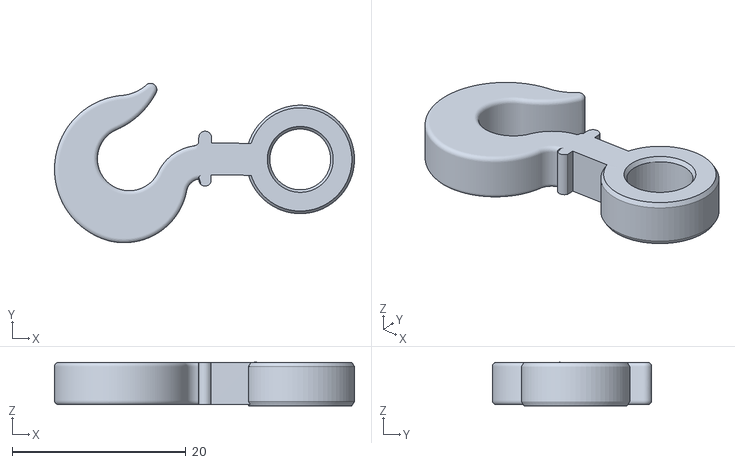
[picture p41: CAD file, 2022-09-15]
STL/Ganxo/Hook_x1.stl
34.6 x 18.4 x 5.01

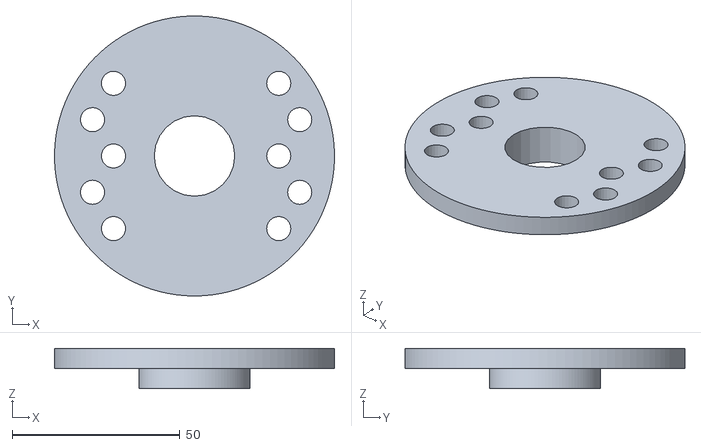
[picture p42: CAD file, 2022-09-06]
STL/PlataformaGiratoria/DiscEngranatge_x1.stl
83.5 x 83.5 x 12.0

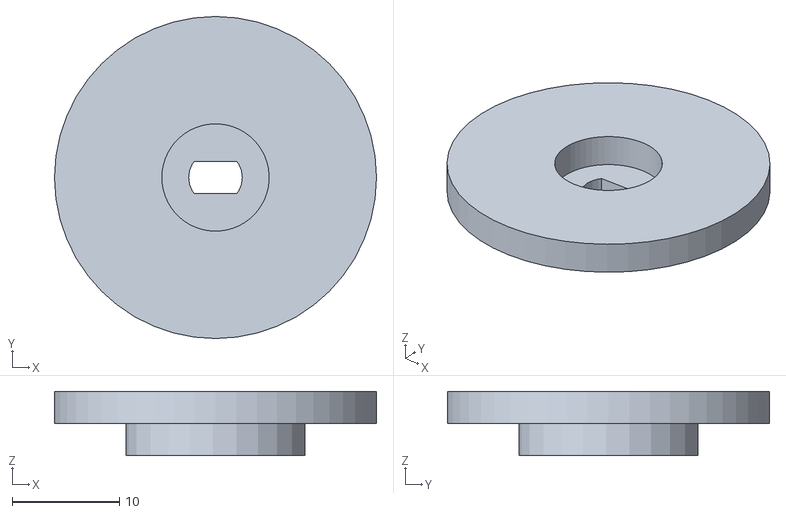
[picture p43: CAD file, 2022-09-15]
STL/Base/Spool28BYJ-48_2.stl
30.0 x 30.0 x 6.00

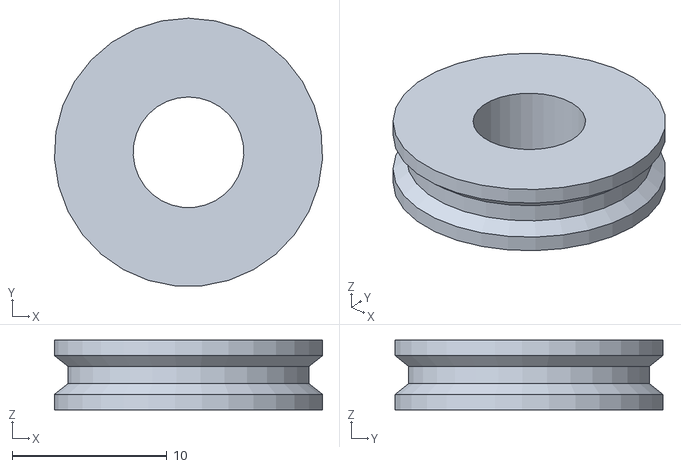
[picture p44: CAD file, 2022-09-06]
STL/Ganxo/Pulley_x1.stl
17.3 x 17.3 x 4.50

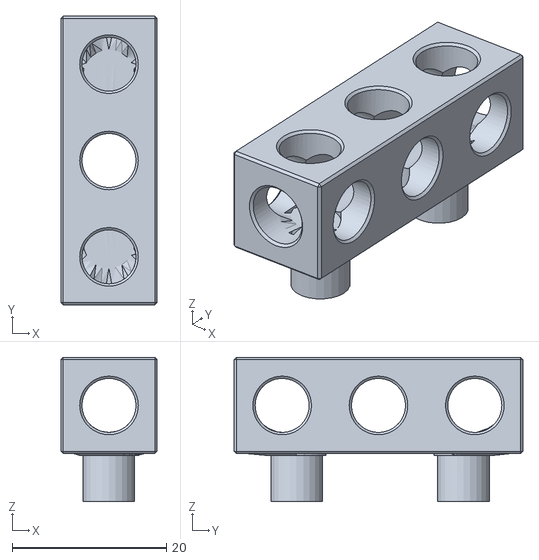
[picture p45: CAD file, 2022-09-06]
STL/PlataformaGiratoria/BlocGrua3x1_x2.stl
12.5 x 37.5 x 18.7

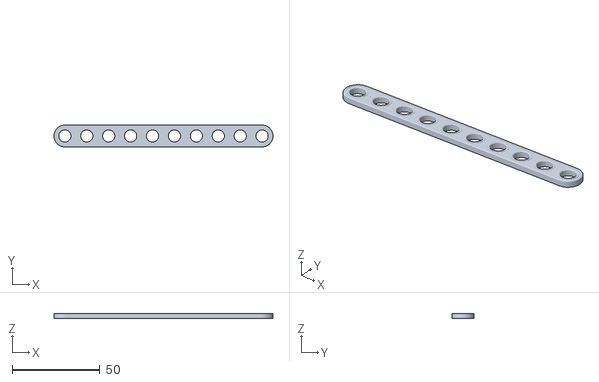
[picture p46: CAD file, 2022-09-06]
STL/Ploma/Brace10_x2.stl
124.9 x 12.5 x 3.12

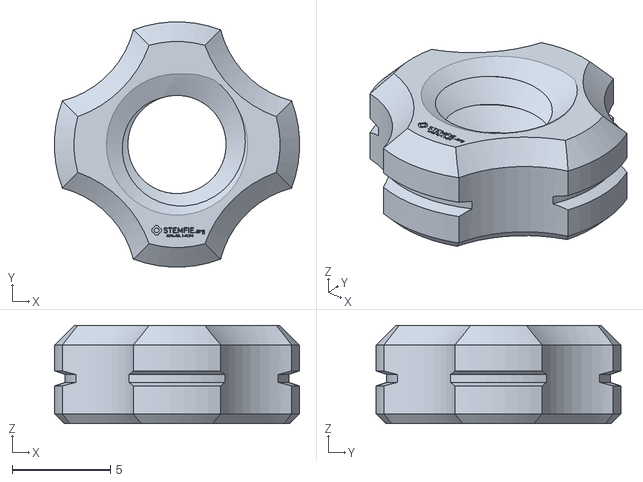
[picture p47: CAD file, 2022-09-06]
STL/Base/Nut5mm_x64.stl
12.5 x 12.5 x 5.00

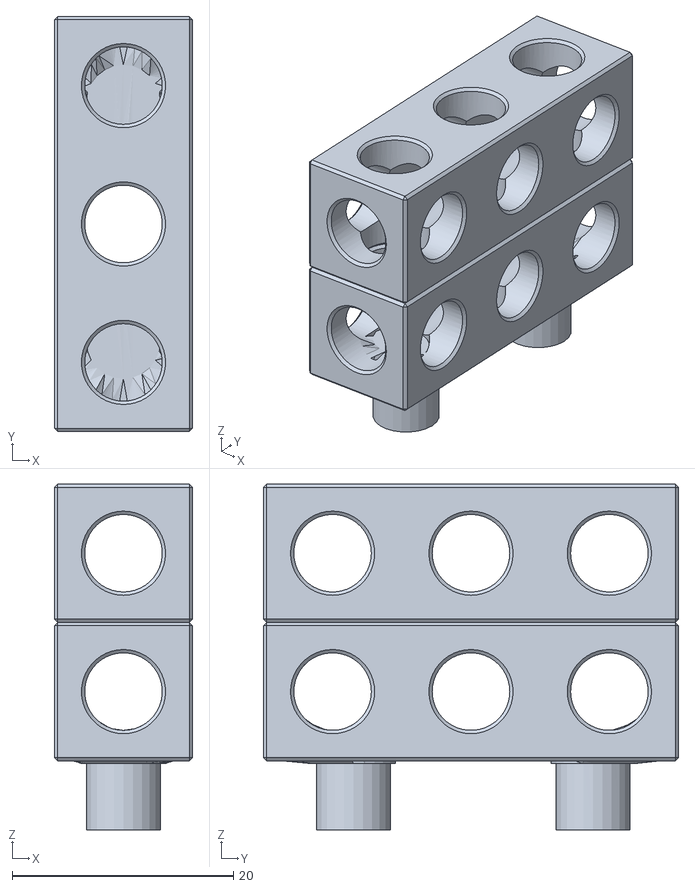
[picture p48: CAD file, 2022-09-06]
STL/PlataformaGiratoria/BlocGrua3x2_x2.stl
12.5 x 37.5 x 31.2

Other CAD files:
STL/Base/28BYJ-48_2H_Stemfie_x1.stl
STL/PlataformaGiratoria/EngranatgeGrua_x1.stl
STL/Ploma/PinBU03.75_x1.stl
STL/Base/Spool28BYJ-48_1.stl
STL/Base/28BYJ-48_4H_Stemfie_x1.stl
STL/Base/Arandela2.5mm_x4.stl
STL/Base/Base8x10_x1.stl
STL/Base/Brace13_x4.stl
STL/Base/Brace18_x4.stl
STL/Base/Gear28BYJ-48_130mm_x1.stl
STL/Base/STR_STD_BRM-4x3_x1.stl
STL/Ploma/Beam14_x3.stl
STL/Ploma/Beam18_x2.stl
STL/Ploma/Beam3_x1.stl
STL/Ploma/Beam4_x1.stl
STL/Ploma/Beam5_x2.stl
STL/Ploma/Beam6x2_x1.stl
STL/Ploma/Beam7T3_x2.stl
STL/Ploma/Brace12_x2.stl
STL/Ploma/Brace2_x8.stl
STL/Ploma/Brace4_x6.stl
STL/Ploma/Brace6_x3.stl
STL/Ploma/Brace8_x1.stl
STL/Ploma/NutFixed_x17.stl
STL/Ploma/PinBU00.50x2.stl
STL/Ploma/PinBU01.25_x4.stl
STL/Ploma/PinBU01.50_x16.stl
STL/Ploma/PinBU01.75_x4.stl
STL/Ploma/PinBU02.50_x4.stl
STL/Ploma/PinBU05.75_x1.stl
STL/Ploma/PulleyBU1.00_x3.stl
STL/Ploma/ScrewBU01.25_x10.stl
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

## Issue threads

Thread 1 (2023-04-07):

Software for Arduino?

topse, 2023-04-07:
Hi,
I'd like to build the crane... could you also provide the software?

Best Regards,
Tobias

maynej, 2023-04-08:
Hi Tobias
Sorry, I haven't finished the software yet and it's very simple. I need wiring some parts to do the full tests. I hope I can finish it as soon as possible. The problem is that I do a lot of tasks and the simple ones are left pending... You programming in Arduino C++ ?   I programming also in ArduinoBlocks, easy and a lot examples for to do. Regards Jordi

topse, 2023-04-08:
Hi Jordi,
thanks for your answer... I understand... If I come up with something useful, I will share :-) Thanks for the great projekt!

Best Regards,
Tobias

maynej, 2023-04-08:
I'm retired, but need more time every day to do all tasks, family, hobbies .... Your input is well for me, I will start to finish... if you want my email is maynejordi@hotmail.com youcan send me an email and I will show you the schematic and more. Regards
